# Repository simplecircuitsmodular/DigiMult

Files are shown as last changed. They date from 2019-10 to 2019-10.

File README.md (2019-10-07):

# DigiMult

The DigiMult features 2 DAC outputs, a trigger input, and an analog input as well as 4 potentiometers and a switch. The module can be programmed using the Arduino IDE. 

Shortly after I started designing this module, CCTV announced the Cascadence. Since my design and CCTV's were almost identical, I decided to make this module compatable with theirs. There are only 4 differences between them:
- The DigiMult is all through hole, making it easier to solder.
- The DigiMult is 8hp instead of 4hp. This is due to the larger through hole components.
- The DigiMult feaures an analog input, which is absent from the Cascadence.
- The DigiMult switch is on pin rather than pin to free up an analog pin for the input.

Information on the Cascadence can be found at [CCTV's website](https://www.cctv.fm/product-page/cascadence) and [their GitHub page](https://github.com/cctvfm/cascadence).

A template.ino and information on modifying CCTV's software to work with the DigiMult will be added soon.

## Files
### DigiMult_xx .brd and .sch
These are the board and schematic files needed to manufacture PCBs. Gerbers need to be generated in Eagle for manufacturing.

### DigiMultParts_xx.md
These are the parts lists for each module. A mouser BOM is available in this file as well.

### DigiMult.ai
These are the panels in Adobe Illustrator format. I make my panels on a laser cutter with 1/8 inch acrylic.

## Updates

### 01 07OCT19
Initial upload. Design is currently untested.

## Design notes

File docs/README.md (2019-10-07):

# DigiMult

#### [Overview](#overview) | [Design](#design)

### Overview

The DigiMult features 2 DAC outputs, a trigger input, and an analog input as well as 4 potentiometers and a switch. The module can be programmed using the Arduino IDE. 

### Design

This module leverages work done by CCTV on their Cascadence module. My design is compatible with their software, but includes an analog input and uses all through hole parts.

### Buy

I'll be updating this part soon with a link to buy PCBs on Reverb. For the time being you can email me to purchase development PCBs at a discount. These will be fully functional but have minor issues.

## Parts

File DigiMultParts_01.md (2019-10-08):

#Parts List

Mouser BOM: Coming Soon

| Name | Part | Package | Source |
| --- | --- | --- | --- |
| R1-R4 | Potentiometer, 10k | Alpha 9mm | Mouser |
| U1 | ATTiny 84 | DIP 14 | Mouser |
| JP1 | Pin Header, 2x5 | 2.54mm pitch | Mouser |
| JP2 | Pin header, 2x3 | 2.54mm pitch | Mouser |
| IC1 | 7805 | 5mm | Mouser |
| IC2 | MCP42 | DIP 8 | Mouser |
| IC3 | TL072 | DIP 8 | Mouser |
| R5-R8, 14 | Resistor, 10k | Axial TH | Mouser |
| R9-R11 | Resistor, 1k | Axial TH | Mouser |
| R12 | Resistor, 100k | Axial TH | Mouser |
| R13 | Resistor, 33k | Axial TH | Mouser |
| U$1-4 | Mono Jack | Thonkiconn | Modular Addict |
| C1-C3 | Capacitor, 10u | 5mm radial | Mouser |
| S1 | Toggle, SPDT, on-on | Mini | Mouser |
| T1 | Transistor, 2n2222 | Through Hole | Mouser |
| LED1 | LED, any color | 3mm | Mouser |

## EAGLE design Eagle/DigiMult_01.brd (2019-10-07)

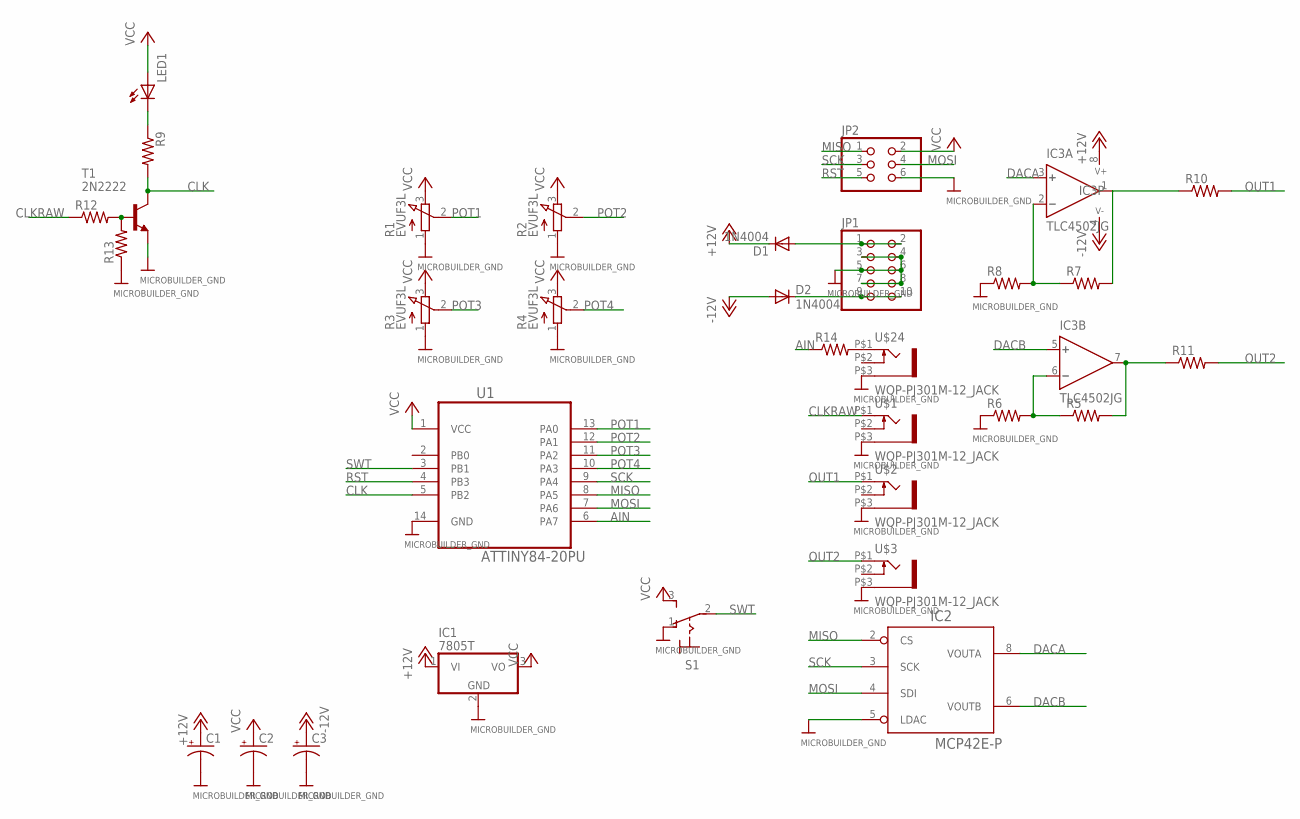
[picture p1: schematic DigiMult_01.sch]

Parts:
C1, C2, C3: CPOL-USE2.5-5; E2,5-5
D1, D2: 1N4004; DO41-10
IC1: 7805T; TO220H
IC2: MCP42E-P; DIL08
IC3: TLC4502JG; DIL08
JP1: PINHD-2X5/OCT; 2X05
JP2: PINHD-2X3/OCT; 2X03
LED1: LED3MM
R1, R2, R3, R4: EVUF3L; EVUFXL
R5, R6, R7, R8, R9, R10, R11, R12, R13, R14: R-US_0204/2V; 0204V
S1: M9040P
T1: 2N2222; TO92-EBC-OVAL
U1: ATTINY84-20PU; DIP254P762X533-14
U$1, U$2, U$3, U$24: WQP-PJ301M-12_JACK

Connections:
+12V: C1.+, D1.C, IC1.1 (VI), IC3.8 (V+)
-12V: C3.+, D2.A, IC3.4 (V-)
AIN: R14.1, U1.6 (PA7)
CLK: R9.2, T1.C, U1.5 (PB2)
CLKRAW: R12.1, U$1.P$1 (2)
DACA: IC2.8 (VOUTA), IC3.3 (+)
DACB: IC2.6 (VOUTB), IC3.5 (+)
GND: C1.-, C2.-, C3.-, IC1.2 (GND), IC2.5 (LDAC), IC2.7 (GND), JP1.3, JP1.4, JP1.5, JP1.6, JP1.7, JP1.8, JP2.6, R1.1 (A), R2.1 (A), R3.1 (A), R4.1 (A), R6.1, R8.1, R13.1, S1.1 (O), T1.E, U1.14 (GND), U$1.P$3 (1), U$2.P$3 (1), U$3.P$3 (1), U$24.P$3 (1)
MISO: IC2.2 (CS), JP2.1, U1.8 (PA5)
MOSI: IC2.4 (SDI), JP2.4, U1.7 (PA6)
unnamed: LED1.K (C), R9.1
unnamed: IC3.7 (OUT), R5.2, R11.1
unnamed: IC3.1 (OUT), R7.2, R10.1
unnamed: R12.2, R13.2, T1.B
unnamed: D1.A, JP1.1, JP1.2
unnamed: IC3.2 (-), R7.1, R8.2
unnamed: IC3.6 (-), R5.1, R6.2
unnamed: D2.C, JP1.9, JP1.10
unnamed: R14.2, U$24.P$1 (2)
OUT1: R10.2, U$2.P$1 (2)
OUT2: R11.2, U$3.P$1 (2)
POT1: R1.2 (S), U1.13 (PA0)
POT2: R2.2 (S), U1.12 (PA1)
POT3: R3.2 (S), U1.11 (PA2)
POT4: R4.2 (S), U1.10 (PA3)
RST: JP2.5, U1.4 (PB3)
SCK: IC2.3 (SCK), JP2.3, U1.9 (PA4)
SWT: S1.2, U1.3 (PB1)
VCC: C2.+, IC1.3 (VO), IC2.1 (VCC), JP2.2, LED1.A, R1.3 (E), R2.3 (E), R3.3 (E), R4.3 (E), S1.3 (S), U1.1 (VCC)

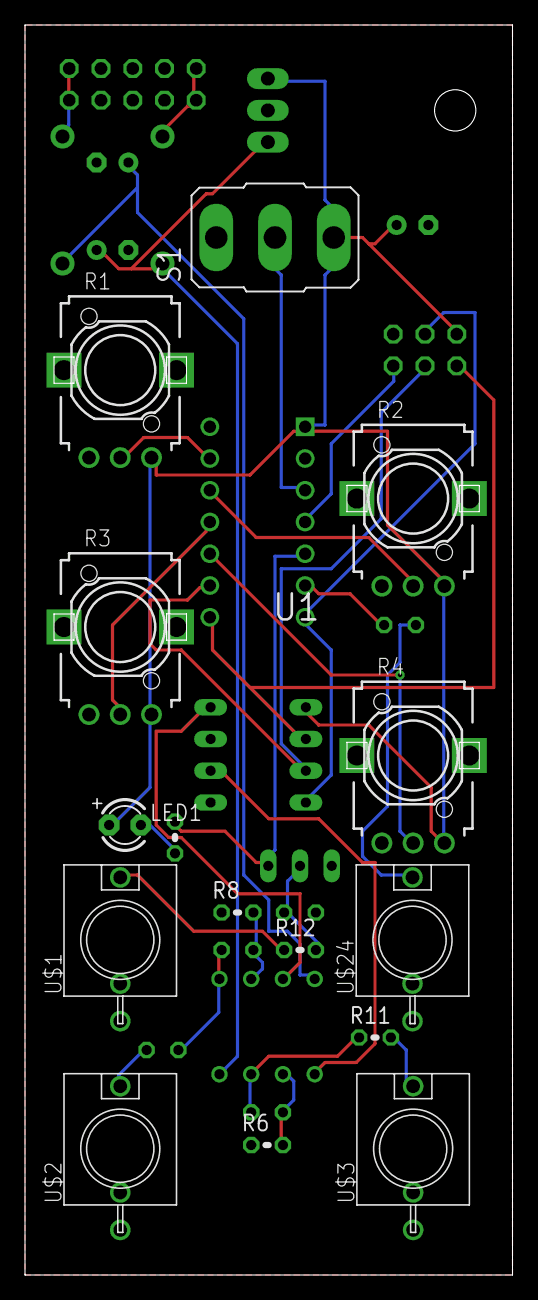
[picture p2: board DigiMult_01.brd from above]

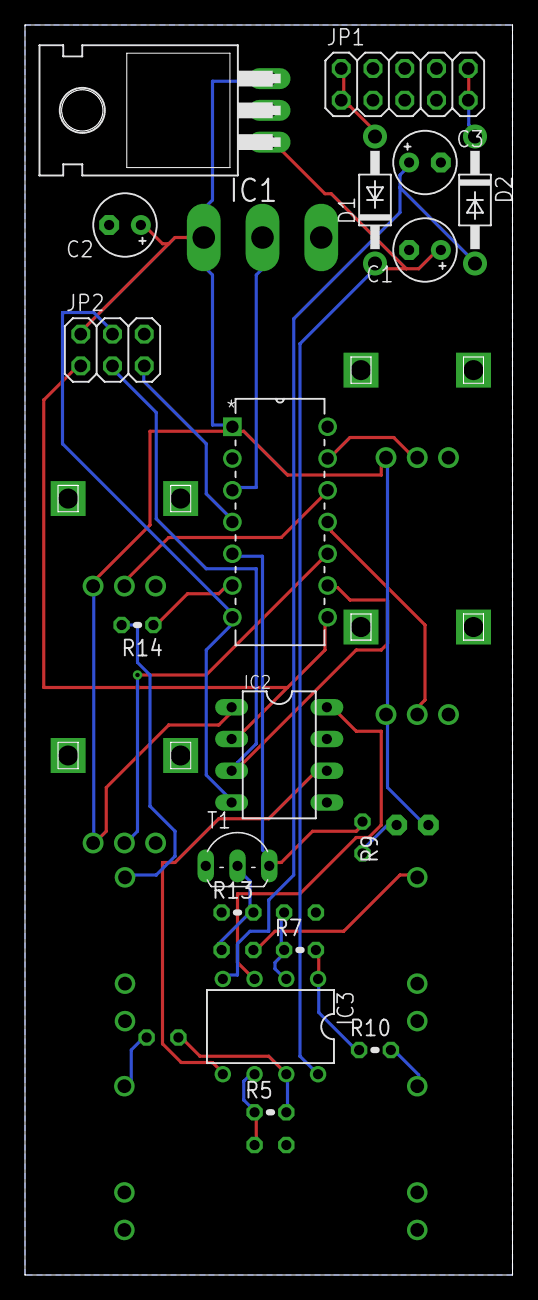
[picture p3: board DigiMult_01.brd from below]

Board: 2 copper layers, 39.0 x 100.0 mm, 32 parts (17 on the bottom side), 29 nets.
